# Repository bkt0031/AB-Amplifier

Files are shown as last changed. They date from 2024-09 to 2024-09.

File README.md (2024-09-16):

# Class AB Monaural 2 Watt Amplifier

With regards to class AB audio amplifiers there is really nothing new under the sun, and this design is no exception.

I have a collection of amateur radio transceivers I built as kits from QRP Labs that the audio ouput can only drive small
headphones (earbuds). Personally I cannot stand having earbuds in my ears for long durations, so I wanted to make an
audio amplifier to drive a speaker I reprovisioned from a commercial mobile radio. 

My requirements for the audio amplifier was:

* Run off of a 12 VDC, single rail, power supply
* Drive a 4 Ohm speaker
* Loud enough for a typical size room with enough volume to overcome any incidental noise/sounds
* Needs to be an analog class of operation - please, no switching...
* I don't want to waste power - needs efficiency
* Power switch
* Power input on a 2.1x5.5 mm panel jack
* Power indicator
* Volume control

Loudness requirements is a bit nebulous to me as I have no clue as to how the sound pressure levels from
the speaker relate to the wattage applied to the speaker. In this case I decided to just go for the maximum
that I could get from a 12 VDC single rail supply, which I know is not much really in my way of thinking.

My general conclusion is to use a class AB amplfier, and the ultimate circuit I ended up with is
based on the design of *The Tube Roaster* channel on [YouTube](https://www.youtube.com/watch?v=THRFZiEfnnA). 
The largest difference was the supply voltage he was using and my 12 VDC supply requirement. I ended
up entering the circuit in [QSpice](https://www.qorvo.com/design-hub/design-tools/interactive/qspice/), tweaking
the bias resistors till I got even clipping on the output. The resulting circuit looks like:

QSpiceSchematic

The net simulate results were maximum unclipped output voltage across the 4 Ohm load of 8.1 Vp-p which results in around
2 Watts being delivered to the load. The simulated unclipped gain was 23.1 dB at 1 KHz.

The only oddity of this circuit is the boostrapping capacitor C4. Based on what little I know about boostrapping it has
the effect of reducing the AC current through R7 which effectively raises the collector AC resistance on the input common-emitter
amplifier (Q1). Running the simulation with and without C4 show the gain to increase around 3 dB with the bootstrapping circuit
in place.

After building this circuit I ended up with about 8.23 Vp-p unclipped maximum output voltage which will deliver 2.1 Watts to
the 4 Ohm speaker.

## External Case Mounted Parts

| Qty | Description | Distributor  | Part Number | Notes |
| :---- | :--- | :--- | :--- | :--- |
| 1 | POT 1K OHM 1/2W PLASTIC LINEAR | Digi-Key | 53AAD-B28-B10L-ND | Overkill - lol |
| 1 | Toggle Switch SPST Panel Mount | Digi-Key | 360-MN11ES1W01-ND | |
| 1 | LED 3MM PANEL MNT W/24AWG LEADS | Digi-Key | SSI-LXR3612ID-150-ND | |
| 1 | CONN JACK MONO 3.5MM PNL MNT | Digi-Key | SC1455-ND | |
| 1 | CONN RCA JACK MONO 3.2MM PNL MT | Digi-Key | CP-1412-ND | No locating features |
| 1 | CONN PWR JACK 2.0X5.5MM SOLDER | Digi-Key | CP-5-ND | |

## PCB Layout

AB-Amplifier_PCB

## Amplifier Enclosure

The case was printed using ABS filament. I always have a problem with determining hole size for the threaded heat
inserts. In my case the standoff hole sizes were a tad small and I needed to increase the hole size so that 
the head insert would go in without deforming the standoff.

## Future Ideas
* Mute button
* Headphone jack integration
* Use surface mount components to reduce size
* Smaller output transistors and heatsinks. In the current design these are barely getting warm at full power output

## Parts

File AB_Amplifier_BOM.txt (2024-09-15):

Qty	Reference	Description	Value	WVDC	Distributor	PartNo
1	C2	CAP ALUM 220UF 20% 25V RADIAL TH	220u	25	DigiKey	1572-1705-ND
1	C3	CAP CER 22PF 50V C0G/NP0 RADIAL	22p	50	DigiKey	BC5146-ND
1	C4	CAP ALUM 68UF 20% 25V RADIAL	68u	25	DigiKey	1189-2243-ND
1	C6	CAP ALUM 470UF 20% 25V RADIAL	470u	25	DigiKey	399-18264-1-ND
2	C1,C8	CAP ALUM 100UF 20% 25V RADIAL TH	100u	25	DigiKey	1572-1659-ND
2	C5,C7	CAP CER 0.1UF 50V X7R RADIAL	0.1u	50	DigiKey	BC1084TR-ND
2	HS1,HS2	HEATSINK TO-220 BLACK 1"	Heatsink		DigiKey	HS231-ND
1	J2	CONN HEADER VERT 3POS 2MM	3 Pos		DigiKey	455-B3B-PH-KL-ND
2	J1,J5	CONN HEADER VERT 2POS 2MM	2 Pos		DigiKey	455-1704-ND
3	J3,J4,J6	CONN HEADER VERT 2POS 2MM	2 Pos		DigiKey	455-B2B-XH-A-ND
1	Q3	TRANS PNP 40V 0.2A TO92	2N3906		DigiKey	497-2404-ND
1	Q5	TRANS PNP 100V 3A TO220	TIP32C		DigiKey	497-2628-5-ND
1	Q6	TRANS NPN 100V 3A TO220	TIP31C		DigiKey	497-2615-5-ND
3	Q1,Q2,Q4	BJT TO92 40V NPN 0.625W 150C	2N3904		DigiKey	497-2395-ND
1	R1	RES 4.7K OHM 1% 1/4W AXIAL	4.7K		DigiKey	13-MFR-25FTE52-4K7CT-ND
1	R2	RES 15K OHM 1% 1/4W AXIAL	15K		DigiKey	13-MFR-25FTE52-15KCT-ND
1	R3	RES 82K OHM 1% 1/4W AXIAL	82K		DigiKey	13-MFR25SFTE52-82KCT-ND
1	R4	RES 150 OHM 1% 1/4W AXIAL	150		DigiKey	13-MFR-25FTE52-150RCT-ND
1	R5	RES 1K OHM 1% 1/4W AXIAL	1K		DigiKey	13-MFR-25FRF52-1KTR-ND
1	R6	RES 3.3K OHM 1% 1/4W AXIAL	3.3K		DigiKey	13-MFR-25FTE52-3K3CT-ND
1	R7	RES 1.5K OHM 1% 1/4W AXIAL	1.5K		DigiKey	13-MFR-25FTE52-1K5CT-ND
1	R8	RES 1.2K OHM 1% 1/4W AXIAL	1.2K		DigiKey	13-MFR-25FTE52-1K2CT-ND
1	R13	RES 4.7 OHM 1% 1/4W AXIAL	4.7		DigiKey	13-MFR-25FTE52-4R7CT-ND
1	R14	RES 560 OHM 1% 1/4W AXIAL	560		DigiKey	13-MFR-25FTE52-560RCT-ND
2	R11,R12	RES 0.22 OHM 1% 1/4W AXIAL	0.22		DigiKey	13-MFR-25FTF52-0R22CT-ND
2	R9,R10	RES 120 OHM 1% 1/4W AXIAL	120		DigiKey	13-MFR-25FTE52-120RCT-ND
1	RV1	TRIMMER 1K OHM 0.5W PC PIN TOP	1K		DigiKey	563-CT-6EP102-ND

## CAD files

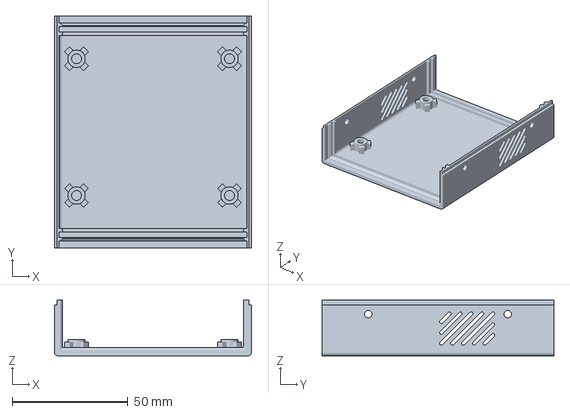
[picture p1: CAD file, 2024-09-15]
EnclosureModels/Lower Shell.3mf
85.0 x 100.0 x 24.0 mm

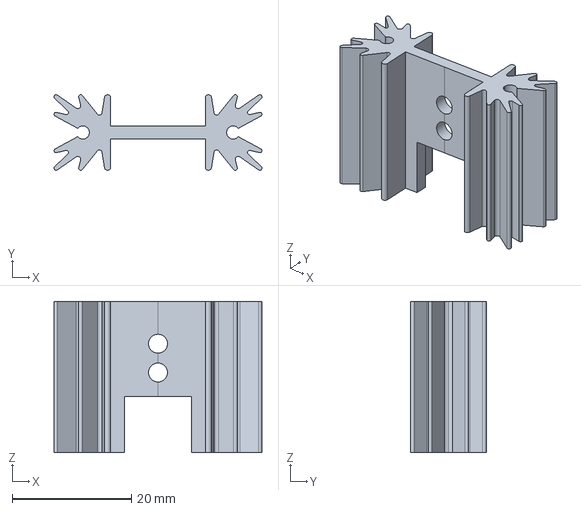
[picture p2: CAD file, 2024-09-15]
PartModels/Aavid_531002B00000G_35x13mm.step
34.9 x 12.7 x 25.4 mm

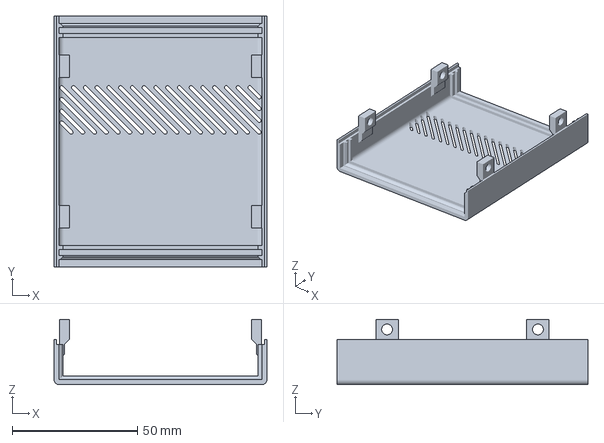
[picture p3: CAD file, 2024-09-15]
EnclosureModels/Upper Shell.3mf
85.0 x 100.0 x 26.0 mm

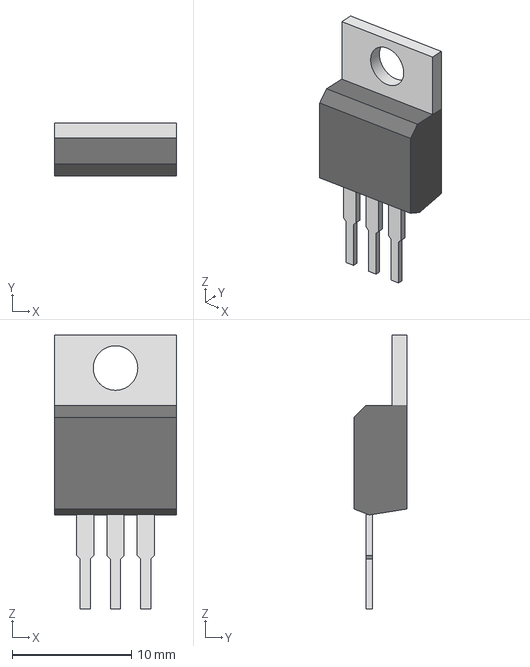
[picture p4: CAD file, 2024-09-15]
PartModels/TO-220-3_Vertical_2.step
10.2 x 4.46 x 23.0 mm

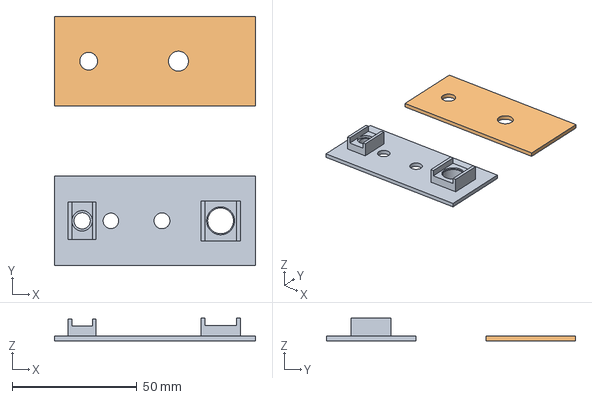
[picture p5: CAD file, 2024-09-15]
EnclosureModels/Front and Rear Plate.3mf
80.6 x 100.0 x 9.18 mm
Front Plate
Rear Face.stl

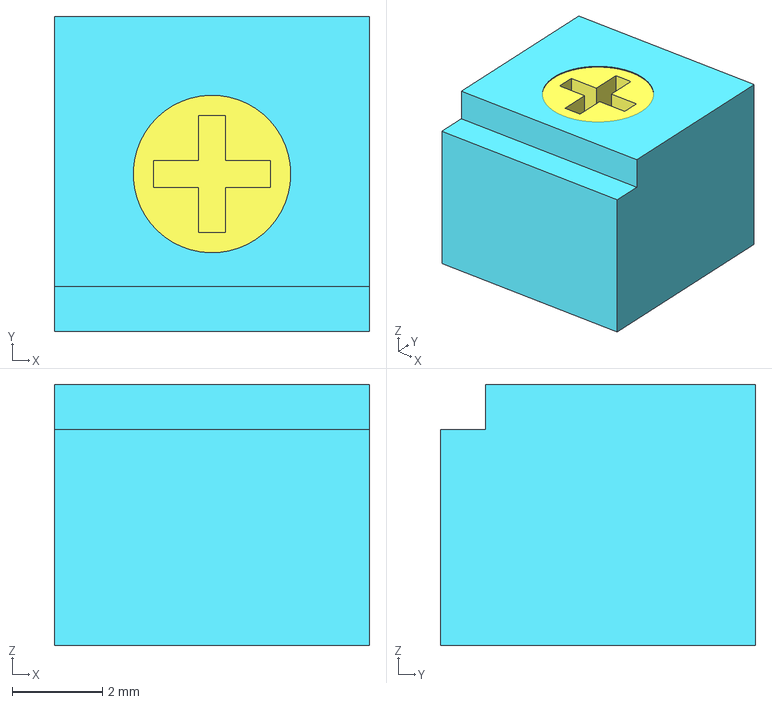
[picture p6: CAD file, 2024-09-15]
PartModels/Potentiometer_Nidec_CT-6_Vertical.step
7.00 x 7.00 x 5.80 mm

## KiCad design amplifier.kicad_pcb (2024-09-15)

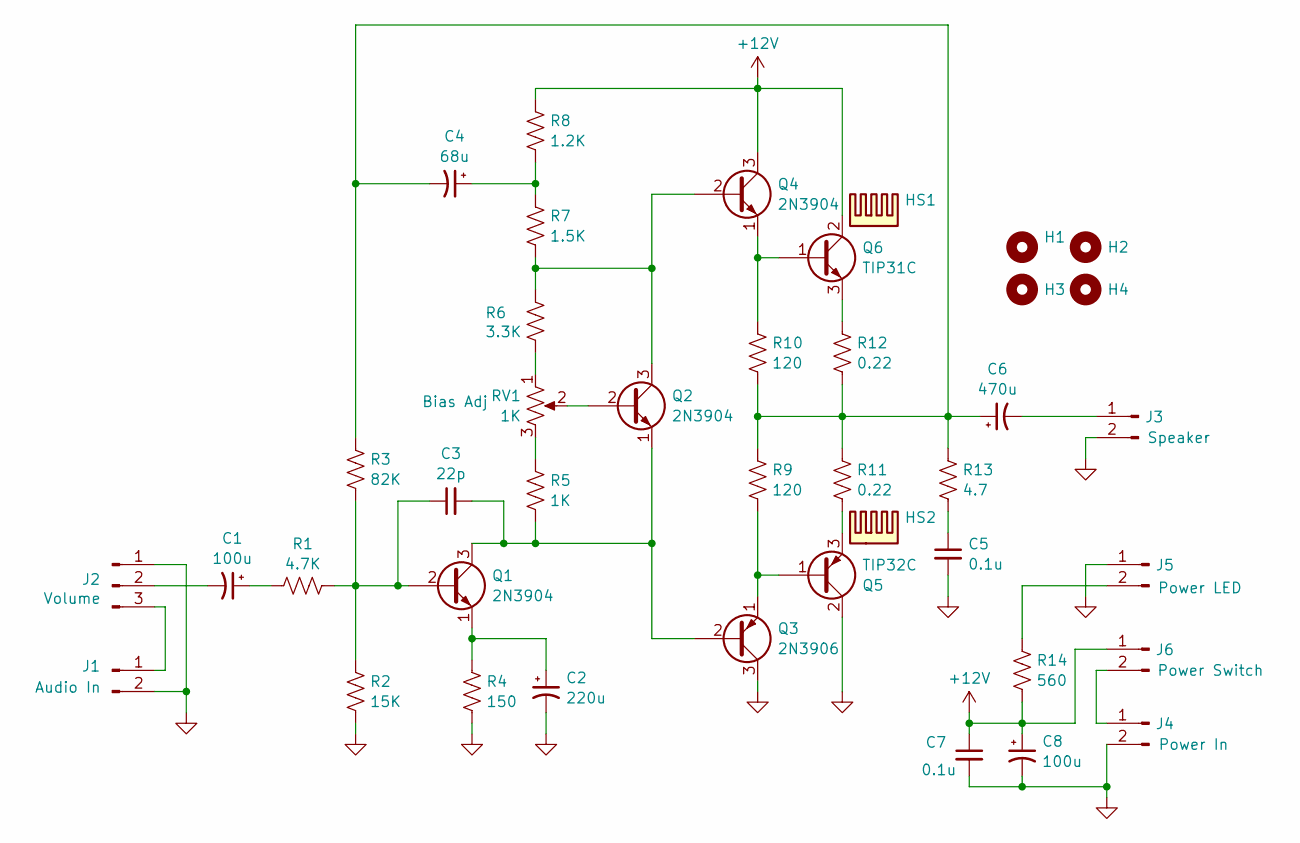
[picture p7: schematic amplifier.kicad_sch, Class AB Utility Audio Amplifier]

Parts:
C1, C8: 100u; CP_Radial_D5.0mm_P2.00mm; PartNo 1572-1659-ND
C2: 220u; CP_Radial_D6.3mm_P2.50mm; PartNo 1572-1705-ND
C3: 22p; C_Rect_L4.0mm_W2.5mm_P2.50mm; PartNo BC5146-ND
C4: 68u; CP_Radial_D5.0mm_P2.00mm; PartNo 1189-2243-ND
C5, C7: 0.1u; C_Rect_L4.0mm_W2.5mm_P2.50mm; PartNo BC1084TR-ND
C6: 470u; CP_Radial_D10.0mm_P5.00mm; PartNo 399-18264-1-ND
H1, H2, H3, H4: MountingHole; MountingHole_3.2mm_M3_ISO7380
HS1, HS2: Heatsink; Aavid_531002B00000G_35x13mm; PartNo HS231-ND
J1, J5: 2 Pos; JST_PH_B2B-PH-K_1x02_P2.00mm_Vertical; PartNo 455-1704-ND
J2: 3 Pos; JST_PH_B3B-PH-K_1x03_P2.00mm_Vertical; PartNo 455-B3B-PH-KL-ND
J3, J4, J6: 2 Pos; JST_XH_B2B-XH-A_1x02_P2.50mm_Vertical; PartNo 455-B2B-XH-A-ND
Q1, Q2, Q4: 2N3904; TO-92; PartNo 497-2395-ND
Q3: 2N3906; TO-92; PartNo 497-2404-ND
Q5: TIP32C; TO-220-3_Vertical; PartNo 497-2628-5-ND
Q6: TIP31C; TO-220-3_Vertical; PartNo 497-2615-5-ND
R1: 4.7K; R_Axial_DIN0207_L6.3mm_D2.5mm_P10.16mm_Horizontal; PartNo 13-MFR-25FTE52-4K7CT-ND
R2: 15K; R_Axial_DIN0207_L6.3mm_D2.5mm_P10.16mm_Horizontal; PartNo 13-MFR-25FTE52-15KCT-ND
R3: 82K; R_Axial_DIN0207_L6.3mm_D2.5mm_P10.16mm_Horizontal; PartNo 13-MFR25SFTE52-82KCT-ND
R4: 150; R_Axial_DIN0207_L6.3mm_D2.5mm_P10.16mm_Horizontal; PartNo 13-MFR-25FTE52-150RCT-ND
R5: 1K; R_Axial_DIN0207_L6.3mm_D2.5mm_P10.16mm_Horizontal; PartNo 13-MFR-25FRF52-1KTR-ND
R6: 3.3K; R_Axial_DIN0207_L6.3mm_D2.5mm_P10.16mm_Horizontal; PartNo 13-MFR-25FTE52-3K3CT-ND
R7: 1.5K; R_Axial_DIN0207_L6.3mm_D2.5mm_P10.16mm_Horizontal; PartNo 13-MFR-25FTE52-1K5CT-ND
R8: 1.2K; R_Axial_DIN0207_L6.3mm_D2.5mm_P10.16mm_Horizontal; PartNo 13-MFR-25FTE52-1K2CT-ND
R9, R10: 120; R_Axial_DIN0207_L6.3mm_D2.5mm_P10.16mm_Horizontal; PartNo 13-MFR-25FTE52-120RCT-ND
R11, R12: 0.22; R_Axial_DIN0207_L6.3mm_D2.5mm_P10.16mm_Horizontal; PartNo 13-MFR-25FTF52-0R22CT-ND
R13: 4.7; R_Axial_DIN0207_L6.3mm_D2.5mm_P10.16mm_Horizontal; PartNo 13-MFR-25FTE52-4R7CT-ND
R14: 560; R_Axial_DIN0207_L6.3mm_D2.5mm_P10.16mm_Horizontal; PartNo 13-MFR-25FTE52-560RCT-ND
RV1: 1K; Potentiometer_Nidec_CT-6_Vertical; PartNo 563-CT-6EP102-ND

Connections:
+12V: C7.1, C8.1, J6.1, Q4.3 (C), Q6.2 (C), R8.1, R14.2
GND: C2.2, C5.2, C7.2, C8.2, J1.2, J2.1, J3.2, J4.2, J5.1, Q3.3 (C), Q5.2 (C), R2.2, R4.2
unnamed: C1.1, R1.2
unnamed: C4.1, R7.1, R8.2
unnamed: C4.2, C6.1, R3.1, R9.1, R10.1, R11.1, R12.2, R13.1
unnamed: C5.1, R13.2
unnamed: J1.1, J2.3
unnamed: C1.2, J2.2
unnamed: C6.2, J3.1
unnamed: J4.1, J6.2
unnamed: J5.2, R14.1
unnamed: C3.1, Q1.2 (B), R1.1, R2.1, R3.2
unnamed: C3.2, Q1.3 (C), Q2.1 (E), Q3.2 (B), R5.2
unnamed: C2.1, Q1.1 (E), R4.1
unnamed: Q2.2 (B), RV1.2
unnamed: Q2.3 (C), Q4.2 (B), R6.1, R7.2
unnamed: Q3.1 (E), Q5.1 (B), R9.2
unnamed: Q4.1 (E), Q6.1 (B), R10.2
unnamed: Q5.3 (E), R11.2
unnamed: Q6.3 (E), R12.1
unnamed: R5.1, RV1.3
unnamed: R6.2, RV1.1

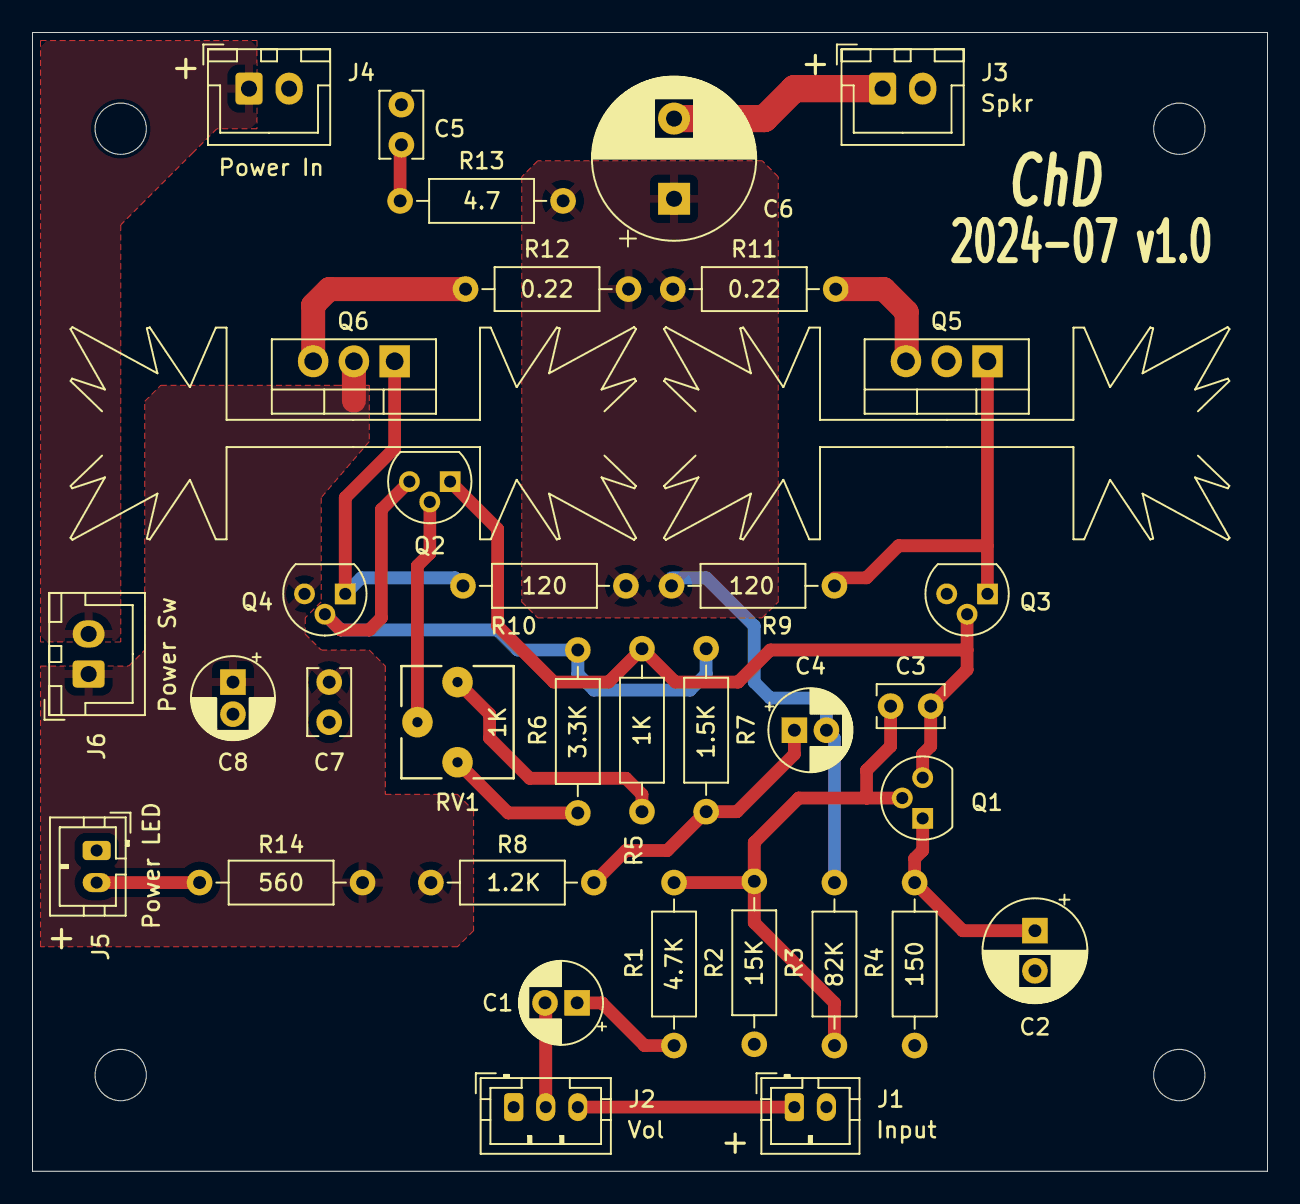
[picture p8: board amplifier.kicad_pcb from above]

Board: 2 copper layers, 77.0 x 71.0 mm, 41 parts (0 on the bottom side), 22 nets.
